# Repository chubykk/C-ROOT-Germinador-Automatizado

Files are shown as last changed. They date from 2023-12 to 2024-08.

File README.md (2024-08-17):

# C-ROOT-Germinador-Automatizado

Facilitar el proceso de germinación de las semillas, permitiendo que sea más eficiente y controlado.

| 5to 2da Avionica | Com: A | Proyecto final 2023 |

Integrantes:

- Misael Castillo // https://github.com/misaacastillo

- Lautaro Cabeza //.

- Bruno Colombo // https://github.com/chubykk

- Mateo Coria //.

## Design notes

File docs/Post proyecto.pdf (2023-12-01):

EEST N°7 - Adquisición de Datos - Profesor Carlassara Fabrizio

POSTPROYECTO DE
“CROOT”

Integrante 1: Cabeza Lautaro Integrante 1:
lautarovalentincabeza@impatrq.com Integrante 2: Castillo Misael Integrante 2: misaelcastillo@impatrq.com Integrante 3: Colombo Bruno Integrante 3:
brunocolombogenlot@impatrq.com

### 1. IDEA PRINCIPAL

El proyecto busca facilitar el proceso de germinación de las semillas, permitiendo que sea más eficiente y controlado. Este tipo de proyecto involucra la construcción de un dispositivo que puede controlar la humedad, temperatura y luz necesarios para la germinación de las semillas. Además, el dispositivo estaría equipado con sensores que monitorean y ajustan
automáticamente estas
condiciones para optimizar el proceso de germinación. La automatización del germinador también permitiría un mayor control de la calidad de las plantas que se producen, lo que puede ser útil tanto para la agricultura comercial como para la producción de alimentos en el hogar.

### 2. PROBLEMAS Y SOLUCIONES DEL PROYECTO

Durante el transcurso del
proyecto se nos han presentado diferentes complicaciones en las siguientes tres áreas:
- Código.
- Diseño de estructura.
- Armado de circuito.

### 2.1 CÓDIGO

El código en su mayoría se resolvió de manera eficiente y sin errores, sin embargo, se complicó el ámbito de la página web donde se mostrarán los datos recopilados. En un
principio habíamos usado
apache para hostear un servidor en una raspberry pi 2 y ahí construir nuestra web, luego lo terminamos cambiando por flask, ya que se programa en su
mayoría con python y nos dejaba un intercambio de datos entre el servidor y el proyecto. Llegando las instancias previas a la exposición apareció el problema, ya que si entrabamos a la web con un dispositivo conectado al mismo internet que la raspberry pi 2, podiamos verla
correctamente, pero si
entrabamos desde otro lugar nos aparece un error, eso provocó que a último momento
tuviéramos que encontrar una página web publica que nos permite enviarle datos y que los muestre, esta página se llama ThingSpeak.

### 2.2 DISEÑO DE

ESTRUCTURA

- El diseño de la estructura en un principio se comenzó a hacer en el programa Blender, al tener complicaciones tales como: no poder realizar los agujeros necesarios en la estructura, cortés en la pieza, etc. Tomamos la decisión de empezar desde 0 el diseño en el programa Fusion 360, donde estas tareas se nos facilitaron.
- Las medidas de los agujeros. Al imprimir en una impresora 3D no tuvimos en cuenta su margen de error, por lo que las medidas al estar hechas exactas, se achicaron unos milímetros los agujeros. Esto lo solucionamos con el minitorno Dremel.
- Problemas en la etapa de riego. Este problema fue muy grave, debido a que los módulos de las plantas no reciben iguales cantidades de agua. Una
solución parcial que
encontramos, fue anular
agujeros para que el riego sea equitativo en todos los módulos. Sin embargo, una solución
óptima que no se llevó a cabo por falta de tiempo, sería un rediseño en la parte superior de la estructura, de manera que tenga una inclinación para que el agua se distribuya de forma similar en los módulos.

### 2.3 ARMADO DE CIRCUITO

- Cuando iniciamos el armado

del circuito pensamos en
comprar una bomba de agua de 12v, pero no conseguimos una q sea apta para nuestro proyecto, es por esto que adquirimos una de 220v y la adaptamos a
nuestro proyecto con una placa de etapa de potencia, para así poder controlar nuestra bomba de 220v con nuestro
microcontrolador raspberry pi pico wifi.

-Problemas con el PCB. Este diseño fue realizado con el programa Proteus 8 y no tuvimos en cuenta el espejismo del pcb, esto causó que los pines donde va nuestro microcontrolador están del revés, La solución fue dar vuelta la raspberry dejándola mal ubicada y soldando algunos cables directo a la raspberry.

### 3. MEJORAS PROPUESTAS

- Deberíamos conseguir una bomba más potente que
nos permita un riego
completo y preciso.
- Mejorar el conexionado de los circuitos y dejarlo de una manera más eficiente
y prolija.
- Terminar y conseguir el
correcto funcionamiento de la página web, así teniéndola personalizada a nuestro gusto y no
tendríamos que usar una
pagina publica sacada de
internet.
- Tenemos tres cables de
alimentación conectados,
uno a 5v, uno a 12v y uno
a 220v. Tendríamos que
conseguir una forma de
reducirlo a un solo cable, dejándolo más estético y
eficiente.
- Relacionado con la
conexión de los circuitos, reutilizamos un pcb hecho
el año pasado, lo que
deberíamos realizar es unir las dos placas en una sola.
- Por último, arreglar todos los cables y demás cosas
que arruinan la estética y la prolijidad del proyecto.

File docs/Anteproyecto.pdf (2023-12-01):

EEST N°7 - Adquisición de Datos - Profesor Carlassara Fabrizio

ANTEPROYECTO DE “TÍTULO DEL PROYECTO”

Integrante 1: Cabeza Lautaro Integrante 1: lautarovalentincabeza@impatrq.com Integrante 2: Castillo Misael Integrante 2: misaelcastillo@impatrq.com Integrante 3: Colombo Bruno Integrante 3: brunocolombogenlot@impatrq.com Integrante 4:
Coria Mateo @mateocoriareartes@impa.trq

### 1. INTRODUCCIÓN

El proyecto busca facilitar el proceso de germinación de las semillas, permitiendo que sea más eficiente y controlado. Este tipo de proyecto involucra la construcción de un dispositivo que puede controlar la humedad, temperatura y luz necesarios para la germinación de las semillas. Además, el dispositivo estaría equipado con sensores que monitorean y ajustan automáticamente estas condiciones para optimizar el proceso de germinación. La automatización del germinador también permitiría un mayor control de la calidad de las plantas que se producen, lo que puede ser útil tanto para la agricultura comercial como para la producción de alimentos en el hogar.

### 2. MARCO DE APLICACIÓN

El germinador de semillas puede ser utilizado en diversas áreas y campos, tales como la agricultura, la horticultura, la producción de alimentos en el hogar, la investigación científica, entre otros.

En el ámbito de la agricultura, el uso de germinadores automatizados puede ser de gran ayuda para la producción de plántulas de alta calidad, que pueden ser utilizadas en la siembra de grandes extensiones de terreno.

En la horticultura, el proyecto puede ser utilizado para producir plántulas ornamentales o comestibles en pequeña escala, en invernaderos o en el hogar. En este caso, el germinador puede ser diseñado para ajustar automáticamente la temperatura y la humedad necesarias para la germinación de las semillas y el crecimiento de las plántulas, lo que simplifica el proceso de cultivo.

En cuanto a la producción de alimentos en el hogar, un germinador de semillas puede ser utilizado para producir brotes de manera fácil y controlada, permitiendo la producción de alimentos frescos y saludables en el hogar. Además, la automatización de este proceso reduce la necesidad de intervención humana y hace que el proceso sea más eficiente y efectivo.

En resumen, el proyecto puede ser implementado en cualquier área que requiera la producción de plántulas o brotes de manera controlada y eficiente, ofreciendo beneficios en la calidad y cantidad de la producción.

### 3. DESCRIPCIÓN TÉCNICA

El germinador de semillas tiene una variedad de componentes y
características. A continuación, se presentan algunas características técnicas que tendrá el proyecto a realizar:
- Un contenedor o cámara para las semillas que se desea germinar.

- Un sistema de riego automatizado que proporciona agua a las semillas y plántulas.
- Un sistema de ventilación.
- Un sistema de iluminación ajustable para proporcionar la cantidad adecuada de luz.
- Sensores de temperatura y humedad para monitorear y controlar las condiciones ambientales dentro del germinador.
- Un microcontrolador o procesador que procesa los datos de los sensores y controla los sistemas de iluminación, riego y ventilación.
- Un software que permite al usuario monitorear y controlar el germinador a través de una interfaz gráfica o una aplicación móvil.

### 3.1 HARDWARE

El hardware estará dividido en tres bloques para una mejor organización del mismo.

3.1.1 BLOQUE DE CIRCUITOS
En el primer bloque podremos encontrar al microcontrolador con sus respectivos circuitos necesarios para que el germinador funcione correctamente. Aquí se incluyen los circuitos controladores del sistema de riego, del sistema de iluminación, de la ventilación y del control de los sensores de temperatura y humedad.

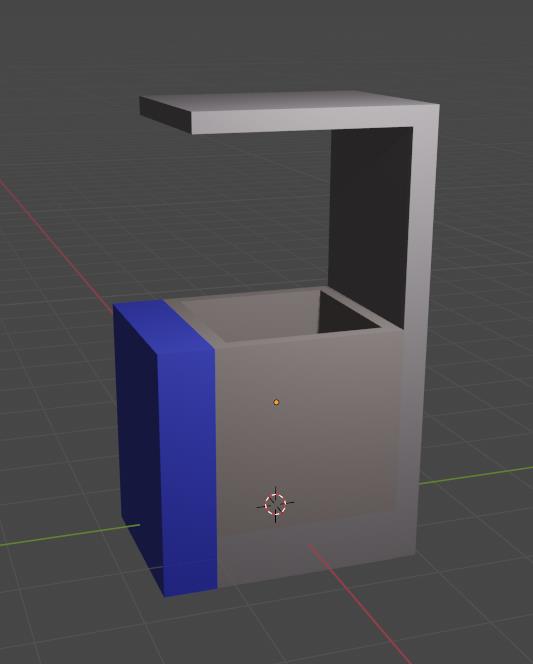
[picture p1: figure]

3.1.2 BLOQUE DE RIEGO
En el segundo bloque encontraremos todo lo relacionado con el sistema de riego, comenzando por el recipiente que contiene el agua utilizada para regar, donde también estará la bomba que se encarga de dirigir el agua por ciertas tuberías con el fin de que llegue hacia unas boquillas las cuales se encargan de rociar las semillas.

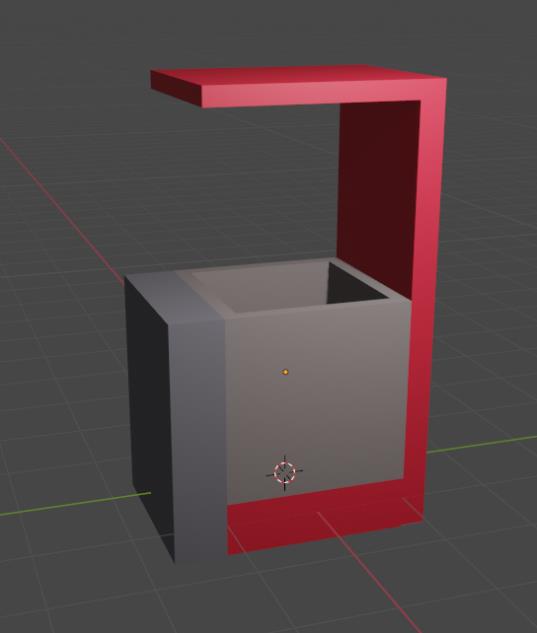
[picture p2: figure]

3.1.3 BLOQUE DE ESTRUCTURA En el tercer bloque se encontrará todo el armado de la estructura donde se ensamblará el germinador, esto incluye el contenedor o cámara para las semillas, los bloques mencionados anteriormente y se le agregan los componentes que serán controlados por los circuitos del primer bloque, como los LEDS del sistema de iluminación y los coolers del sistema de ventilación. También se colocarán los sensores de temperatura y humedad controlados por sus respectivos circuitos.

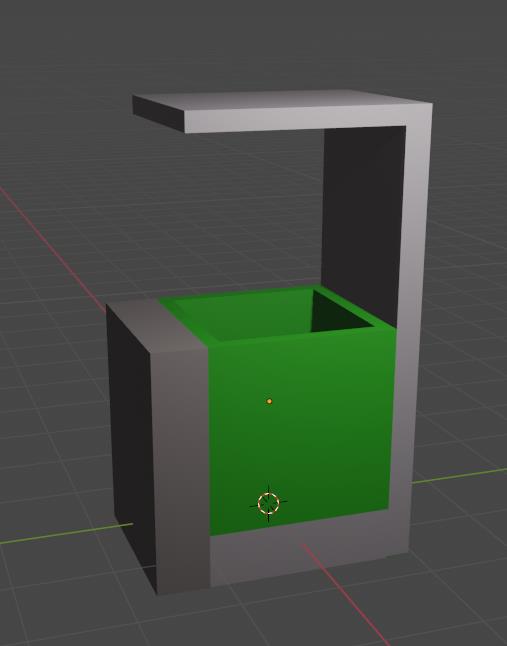
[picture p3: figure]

### 3.2 SOFTWARE

El software del germinador se dividirá en dos partes fundamentales, primeramente, debemos lograr un correcto funcionamiento de los sensores de temperatura y humedad para así lograr un mejor desarrollo de las plántulas.
Luego se verá el diseño de una interfaz gráfica que permita monitorear y controlar el germinador. Esta interfaz debe permitir al usuario ver las condiciones ambientales dentro del germinador (temperatura, humedad, etc.), controlar los sistemas de iluminación, riego y ventilación, además de recibir alertas cuando se produzcan condiciones fuera de los parámetros establecidos.

### 4. DIVISIÓN DE TAREAS

Cabeza, Lautaro: Diseño y armado de circuitos.
Castillo, Misael: Diseño y ensamblaje de la estructura
Colombo, Bruno: Encargado del Software
Coria, Mateo: Ensamblaje de estructura

### 5. LISTA DE MATERIALES

Materiales pensados a usar en el germinador
- Bomba de agua.
- Recipiente de agua.
- Tuberías para el transporte de agua.
- Microcontrolador.
- Sensor de humedad.
- Sensor de temperatura.
- Transformador o fuente.
- Coolers.
- Leds.
- Estructura del germinador.
- Cámara o contenedor para las semillas.

### 6. REFERENCIAS

Referencia utilizada principalmente:

https://www.youtube.com/watch?v=HX2GOmi9i_A

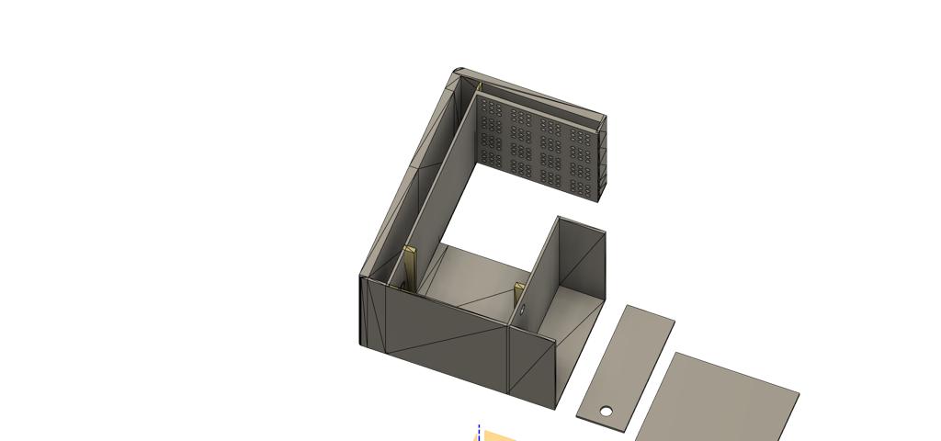
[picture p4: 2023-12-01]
estructura/Imagen de WhatsApp 2023-12-01 a las 14.47.13_d0b760d6.jpg

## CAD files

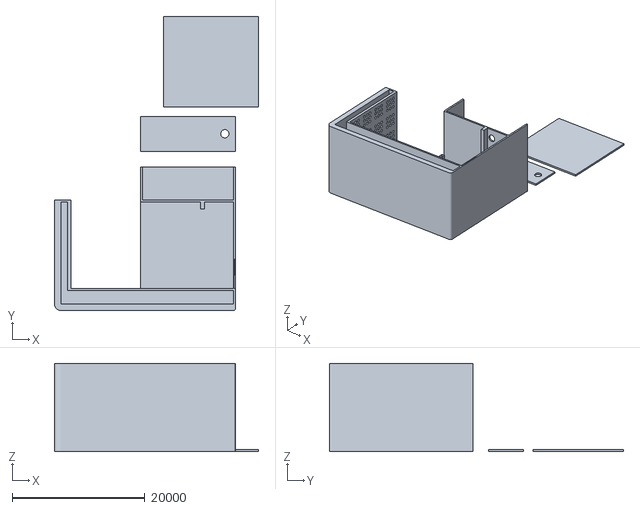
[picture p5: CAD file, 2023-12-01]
estructura/Estructura y caras ult remall v2.stl
30757.7 x 44254.0 x 13300.0

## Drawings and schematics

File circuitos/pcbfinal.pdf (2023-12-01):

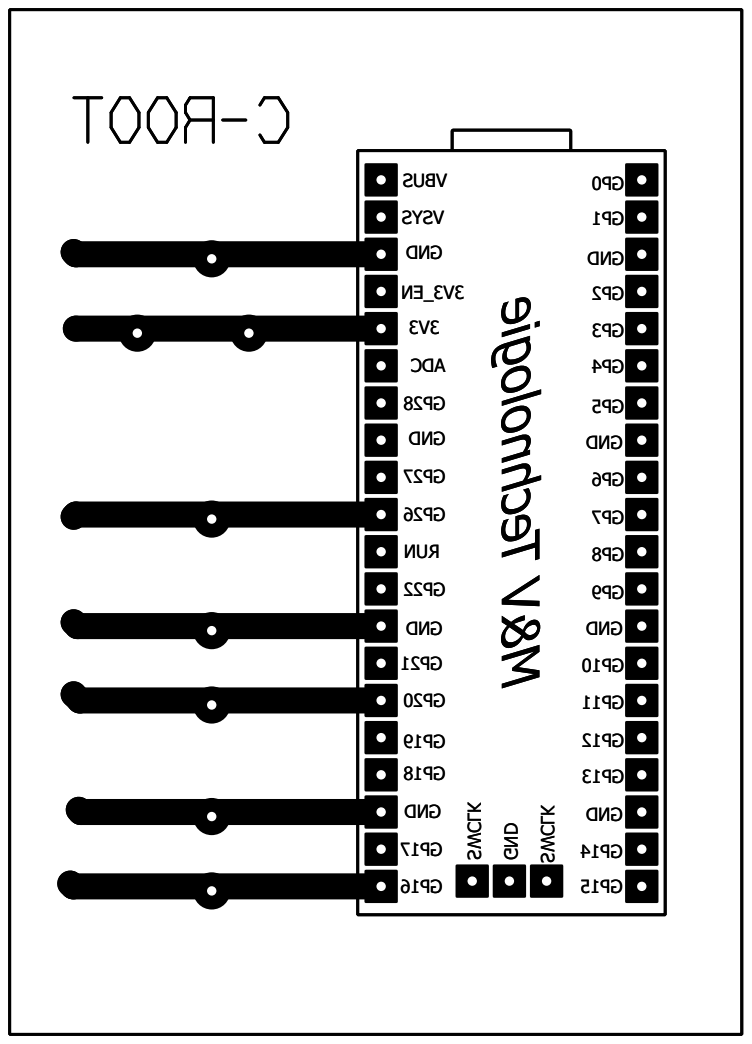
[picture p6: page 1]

DNG DNG DNG DNG
